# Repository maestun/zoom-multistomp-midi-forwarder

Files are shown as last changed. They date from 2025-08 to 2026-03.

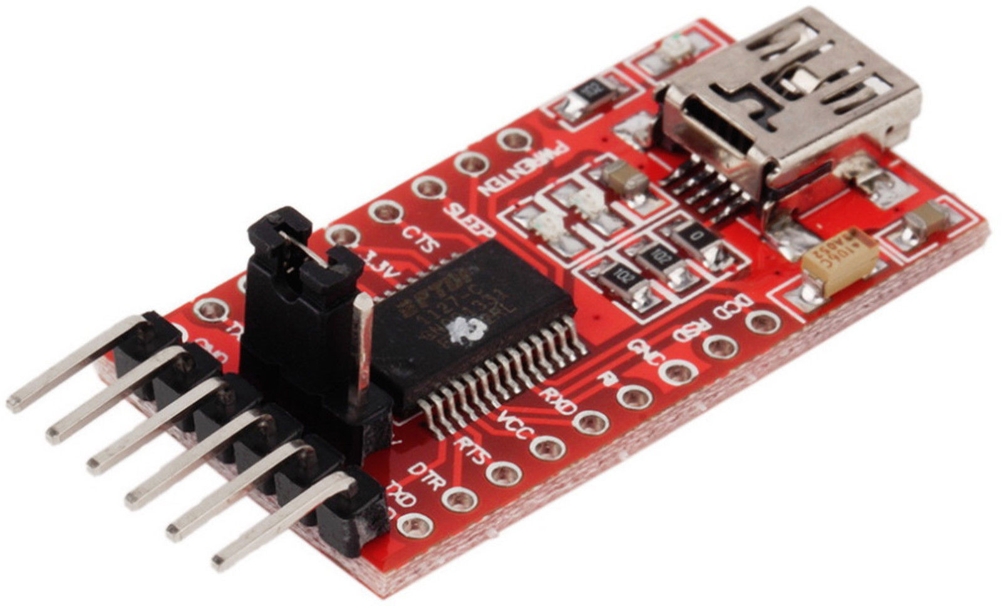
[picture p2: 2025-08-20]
img/FSA.jpg

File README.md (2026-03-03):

# Zoom MultiStomp MIDI forwader

## Features

Enables sending standard MIDI `Program Change` messages thru a standard MIDI DIN-5 socket, to control a Zoom MultiStomp effect pedal thru USB.

## Bill of Materials

- [Arduino Pro Mini (3.3v version)](img/APMv33.jpg)
- [USB Host Shield v2.0](img/UHSv2.jpg)
- [FDTI serial programmer (configured as 3.3v) for code upload](img/FSA.jpg)
- Resistors: 10kΩ, 100kΩ
- Diode: 1n4148 or 1n914
- Optocoupler: 4N28
- 5-pin DIN female socket

## Wiring

```
MIDI IN Socket (5-pin DIN):
Pin 4: Current Source (+5V from MIDI sender)
Pin 5: Current Return (MIDI data return)

Connections:

MIDI Pin 4 ──[220Ω]── 4N28 Pin 1 (LED Anode) ─────────── 1N4148 Cathode
MIDI Pin 5 ────────── 4N28 Pin 2 (LED Cathode) ───────── 1N4148 Anode
                      4N28 Pin 3 N/C

                      4N28 Pin 4 (Emitter)  ──────────- Arduino GND
                      4N28 Pin 5 (Collector) ──[10kΩ]── Arduino VCC (3.3V)
                      4N28 Pin 5 (Collector) ────────── Arduino MIDI_RX_PIN
                      4N28 Pin 6 (Base) ───────[100kΩ]─ Arduino GND
```

## Supported MIDI PC messages

- PC 0 to 49: will set the Zoom pedal to this patch number
- Special PC values: see `eSpecialPC` enum in [main.cpp](src/main.cpp)

## Test w/ zsh

```zsh
for i in {0..100}; do for i in {0..49}; do sendmidi dev "USB2.0-MIDI Port 1" ch 11 pc $i; sleep 0.1; done; done
```

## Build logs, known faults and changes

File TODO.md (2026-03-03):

- [ ] fix MIDI Thru
- [ ] fix usb connection restored after loss
- [ ] design MIDI/optocoupler input PCBs
- [ ] add manual mode (2 footswitches)
- [ ] add screen output

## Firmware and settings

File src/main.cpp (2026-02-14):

#include <Arduino.h>
#include <SoftwareSerial.h>
#include <Usb.h>
#include <usbh_midi.h>
#include "zoom_ms.h"
#include "debug.h"
#include "version.h"

#define MIDI_RX_PIN             7          // SoftwareSerial RX pin for MIDI input
#define MIDI_TX_PIN             -1         // TODO: SoftwareSerial TX pin for MIDI thru ??

#define MIDI_BAUD_RATE          31250   // Standard MIDI baud rate
#define MIDI_STATUS_MASK        0xF0
#define MIDI_CHANNEL_MASK       0x0F
#define MIDI_PROGRAM_CHANGE     0xC0
#define MIDI_IS_STATUS_BYTE(c)  (c & 0x80)
#define MIDI_TIMEOUT_MS         20

// debug / CC commands
enum eSpecialPC {

    TUNER_TOGGLE = 's',
    TUNER_ON = 'T',
    TUNER_OFF = 't',

    GET_DATA = 'd',
    GET_ID = 'i',
    GET_INDEX = 'x',
    GET_VERSION = 'v',

    NEXT_PATCH = 'n',
    PREV_PATCH = 'p',
};

SoftwareSerial  _midi_serial(MIDI_RX_PIN, MIDI_TX_PIN);
ZoomMSDevice    _zoom;

void handle_special_pc(eSpecialPC pc) {
    if (pc == PREV_PATCH) {
        _zoom.incPatch(-1, true);
    }
    else if (pc == NEXT_PATCH) {
        _zoom.incPatch(1, true);
    }
    else if (pc == TUNER_TOGGLE) {
        _zoom.toggleTuner();
    }
    else if (pc == TUNER_ON) {
        _zoom.enableTuner(true);
    }
    else if (pc == TUNER_OFF) {
        _zoom.enableTuner(false);
    }
    else if (pc == GET_DATA) {
        _zoom.requestPatchData();
    }
    else if (pc == GET_INDEX) {
        dprint(F("Current patch index: "));
        int8_t pi = _zoom.requestPatchIndex();
        dprintln(pi);
    }
    else if (pc == GET_ID) {
        _zoom.requestDeviceID();
        dprint(F("Device name: "));
        dprintln(_zoom.getDeviceName());
        dprint(F("Firmware version: "));
        dprintln(_zoom.getFirmwareVersion());
    }
    else if (pc == GET_VERSION) {
        dprint(F("Program version: "));
        dprint(GIT_TAG);
        dprint(F(" - "));
        dprint(GIT_HASH);
        dprint(F(" - "));
        dprintln(GIT_BRANCH);
    }
    else {
        dprint(F("Unknown PC: "));
        dprintln(pc);
    }
}


void handle_midi_input() {
    while (_midi_serial.available()) {
        uint8_t b = _midi_serial.read();
        uint8_t channel = (b & MIDI_CHANNEL_MASK) + 1;
        if (MIDI_IS_STATUS_BYTE(b) && 
            (channel == TARGET_MIDI_CHANNEL)) {
            if ((b & MIDI_STATUS_MASK) == MIDI_PROGRAM_CHANGE) {
                // wait for data byte with timeout (don't block forever)
                unsigned long timeout = millis() + MIDI_TIMEOUT_MS;
                while (!_midi_serial.available() && millis() < timeout) {
                    _zoom.tick();  // keep USB alive while waiting
                }
                if (_midi_serial.available()) {
                    b = _midi_serial.read();
                    if (b < ZOOM_MS_MAX_PATCHES) {
                        // patch number
                        _zoom.sendPatch(b);
                    }
                    else {
                        // special command
                        handle_special_pc((eSpecialPC)b);
                    }
                } else {
                    dprintln(F("MIDI timeout - no data byte"));
                }
            }
        } 
    }
}


void handle_serial_cli() {
    if (Serial.available()) {
        static int patch = 0;
        int c = Serial.read();
        if (c == '+') {
            if (++patch == 50)
            patch = 0;
            _zoom.sendPatch(patch);
        }
        else if (c == '-') {
            if (--patch == -1)
            patch = 49;
            _zoom.sendPatch(patch);
        }
        else {
            handle_special_pc(static_cast<eSpecialPC>(c));
        }        
    }
}


void setup() {
    dprintinit(9600);
    _midi_serial.begin(MIDI_BAUD_RATE);
    _zoom.init();
}

void loop() {
    _zoom.tick();
    handle_midi_input();
    handle_serial_cli();
}

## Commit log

2025-08-20 fix channel check, remove bypass stuff
    [main.cpp]
2025-08-20 added diylc pcb
2025-08-28 fix patch 50 issue
    [main.cpp]
2026-03-03 Add kicad schematic
    [zoom-midi-forwarder.kicad_pcb, zoom-midi-forwarder.kicad_sch]
